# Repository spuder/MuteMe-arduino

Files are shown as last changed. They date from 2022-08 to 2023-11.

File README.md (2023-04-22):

# MuteMe-Arduino

MuteMe-Arduino is an open source implementation of the wildly popular [MuteMe hardware device](https://muteme.com/). 

Visually see if you are muted in a zoom/teams meeting, and control your microphone with the touch of a button. 



  









## CAD

Gerber files are available in the [Gerber](./Gerber/) directory, and available on [https://oshwlab.com/owenspencer/muteme-arduino](https://oshwlab.com/owenspencer/muteme-arduino)

PCB/BOM files are available in the [EasyEDA](./EasyEDA/) directory and available on  [https://oshwlab.com/owenspencer/muteme-arduino](https://oshwlab.com/owenspencer/muteme-arduino)

## Building

**Q: Should you build this?**

Most likely not. An official MuteMe-mini is only $19 with free shipping which is likely about the same or *more* than it would cost to bulid with an arduino. You are highly encouraged to support the origional creators. 

Where this project *does* make sense, is if you have a  mechanical keyboard or macro pad with a micro controller that supports HID emulation, and you want an embedded zoom button. 

- [Adafruit MacroPad](https://www.adafruit.com/product/5128)  
- [Adafruit FeatherWing](https://www.adafruit.com/product/4979)
- [Adafruit NeoPixel](https://www.adafruit.com/product/5020)
- [BYO Keybaord](https://painlessprototyping.com/byo-keyboard/)
- [BYO Keyboard 9 key](https://www.etsy.com/listing/1024993040/byo-9-key-keyboard-kit)

## Hardware

This project is designed around an Arduino Pro Mini, though any Arduino with a 32u4 chip should work (you may need to change pin assignments in the platformio.ini build flags. ItsyBitsy/Feather/Teensy should also work. 

- [Arduino Pro Mini](https://docs.arduino.cc/retired/boards/arduino-pro-mini)  
- [Arduino Pro Micro](https://store-usa.arduino.cc/products/arduino-micro)  
- [ItsyBitsy M0](https://www.adafruit.com/product/3727)  
- [Teensy](https://www.pjrc.com/teensy/)  

If you get a board working and want to add it to the `platformio.ini`, pull requests are welcomed and celebrated. 

### Arduino Pro Micro

On an arduino pro micro, connect the buttons and leds to the following pins. 
Put a ~300-400 ohm resistor on each leg of the RGB Led

You can use a common cathode or common anode LED. If using a common cathod you will need to change the variable `rgbLed_TYPE` 

```
#define BUTTON_PIN 2
#define RED_PIN	  6
#define BLUE_PIN  10
#define GREEN_PIN 9
#define rgbLed_TYPE RGBLed::COMMON_ANODE
```

Note: Pull up resistor on button is not required since Arduino Pro mini has internal pull up on pin 2



(Fritzing file available in the [fritzing](./fritzing/) directory)

## Tech Specs

It is possible to have up to 3 MuteMe devices connected to 1 computer simultaniously, as long as they each have a different VID/PID. The VID/PID MuteMe provides are shown below. 

This repo contains platform.io profiles for all 3. (More than likely you should use 'prototype'.) See [platformio.ini](./platformio.ini)

| Name | VID | PID|
|--- | --- | --- |
| Prototype | 0x16c0 | 0x27db |
| Origional | 0x20a0 | 0x42da | 
| Mini | 0x20a0 | 0x42db | 

Note that regardless of what model you choose, you will most likely see this warning. The official MuteMe devices have an undocumented method for differenciating between current models and the origional kickstarter models. If you figure out how to eliminate this warning, please open an issue or pull request. (Most likely the MuteMe software sends a challenge, or it could be detecting usagePage/usage/serial_number in the HID discriptor.)



Additional information available on the [MuteMe](https://muteme.com/pages/muteme-hid-key) website

Official MuteMe VendorID/ProductId/UagePage/Usage
```
hidapitester --list-detail

20A0/42DB: muteme.com - MuteMe-Mini
  vendorId:      0x20A0
  productId:     0x42DB
  usagePage:     0x0009
  usage:         0x0006
  serial_number:  
  interface:     0 
  path: IOService:/AppleARMPE/arm-io/AppleT600xIO/usb-drd1@2280000/AppleT6000USBXHCI@01000000/usb-drd1-port-hs@01100000/MuteMe-Mini@01100000/IOUSBHostInterface@0/AppleUserUSBHostHIDDevice
```

Compare to an arudino pro mini in USB_SERIAL_HID mode (2 virtual devices)

```
16C0/27DB: SparkFun - SparkFun Pro Micro
  vendorId:      0x16C0
  productId:     0x27DB
  usagePage:     0x0001
  usage:         0x0006
  serial_number: CHIDLD 
  interface:     3 
  path: IOService:/AppleARMPE/arm-io/AppleT600xIO/usb-drd2@2280000/AppleT6000USBXHCI@02000000/usb-drd2-port-hs@02100000/USB2.0 Hub@02100000/AppleUSB20Hub@02100000/AppleUSB20HubPort@02110000/SparkFun Pro Micro@02110000/IOUSBHostInterface@3/AppleUserUSBHostHIDDevice

16C0/27DB: SparkFun - SparkFun Pro Micro
  vendorId:      0x16C0
  productId:     0x27DB
  usagePage:     0xFFC0
  usage:         0x0C00
  serial_number: CHIDLD 
  interface:     2 
  path: IOService:/AppleARMPE/arm-io/AppleT600xIO/usb-drd2@2280000/AppleT6000USBXHCI@02000000/usb-drd2-port-hs@02100000/USB2.0 Hub@02100000/AppleUSB20Hub@02100000/AppleUSB20HubPort@02110000/SparkFun Pro Micro@02110000/IOUSBHostInterface@2/AppleUserUSBHostHIDDevice
  ```

### Input

The MuteMe software sends single hex bytes to the device which lights up a corresponding LED. 

```
red = 0x01
green = 0x02
yellow = 0x03
blue = 0x04
purple(magenta) = 0x05
cyan = 0x06
white = 0x07
noColor = 0x00
```

Note, `noColor` on the official devices actually requires 2 bytes `0x00 0x00`

Data is read using the awesome [HID-Project library](https://github.com/NicoHood/HID). 

```
    while (bytesAvailable--) {
      auto data = RawHID.read();
```

You can view the data that MuteMe software sends with the fantastic [hidapitester](https://github.com/todbot/hidapitester) app

Examples: 

Turn LED Blue
```
# Change '20A0/42DB' to your appropriate VID/PID
hidapitester --list-detail
hidapitester --vidpid 20A0/42DB --open --length 1 --send-feature 0x04 --close
```

Turn LED Magenta with fast blink
```

hidapitester --vidpid 20A0/42DB --open --length 1 --send-feature 0x25 --close
```

Turn off LED
```
hidapitester --vidpid 20A0/42DB --open --length 2 --send-feature 0,0 --close
```

### Output

The physical device sends 4 bytes back to the Mute Me software. 

**Note: MuteMe and hidapitester will have conflicts. You must close the MuteMe software to view output from the physical device** 

Note that while we only need to send 4 bytes, [there is a bug in the HID-Project library](https://github.com/NicoHood/HID/issues/133) that requires `64` bytes be sent. 

02 = Button was released event
```
hidapitester --vidpid 20A0/42DB --open --length 4 --read-input

Opening device, vid/pid: 0x20A0/0x42DB
Reading 64-byte input report 0, 250 msec timeout...read 8 bytes:
 00 00 00 02
Closing device
```

To watch all events as they stream by
```
hidapitester --vidpid 20A0:42DB --open --length 64 --read-input-forever --close
```

When 'holding' the button, MuteMe devices send `0x00 0x00 0x00 0x01` every few hundred milliseconds. 
To prevent overwhelming the USB bus with unneccessary data, MuteMe-Arduino sends that byte every 100 milliseonds which seems to be frequent enough. 

```
Reading 64-byte input report 0, 250 msec timeout...read 8 bytes:
 00 00 00 04 00 00 00 00 00 00 00 00 00 00 00 00 00 00 00 00 00 00 00 00 00 00 00 00 00 00 00 00
 00 00 00 00 00 00 00 00 00 00 00 00 00 00 00 00 00 00 00 00 00 00 00 00 00 00 00 00 00 00 00 00
Reading 64-byte input report 0, 250 msec timeout...read 8 bytes:
 00 00 00 01 00 00 00 00 00 00 00 00 00 00 00 00 00 00 00 00 00 00 00 00 00 00 00 00 00 00 00 00
 00 00 00 00 00 00 00 00 00 00 00 00 00 00 00 00 00 00 00 00 00 00 00 00 00 00 00 00 00 00 00 00
Reading 64-byte input report 0, 250 msec timeout...read 8 bytes:
 00 00 00 01 00 00 00 00 00 00 00 00 00 00 00 00 00 00 00 00 00 00 00 00 00 00 00 00 00 00 00 00
 00 00 00 00 00 00 00 00 00 00 00 00 00 00 00 00 00 00 00 00 00 00 00 00 00 00 00 00 00 00 00 00
 ```

## Debugging

Note: The MuteMe software can only _receive_ input from the arduino if there is only 1 UID per device (e.g. `build_flags = -D USB_HID`). 
Attempting to use `build_flags = -D USB_SERIAL_HID` will allow you to add debugging statements like `Serial.println()`, however it may result in multiple HID devices being registered on a single USB port which can confuse Mute Me software. Any button presses may not be detected by the Mute Me Software while in Serial mode. If you know a way to work arround this limitation, pull requests are welcome and encouraged. 

## Warning

This project is provided for educational purposes only. Comercial products are prohibited.  

MuteMe-Arduino is licensed under the [Creative Commons Non Commercial ShareAlike](https://creativecommons.org/licenses/by-nc-sa/4.0/) license.

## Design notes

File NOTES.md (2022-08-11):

# ZoomMute

Use a microcontroller to mute zoom meetings

## Resources

- [Get PID/VID of usb device](https://kb.synology.com/en-ph/DSM/tutorial/How_do_I_check_the_PID_VID_of_my_USB_device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,view%20its%20PID%20and%20VID.)

Arduino nano

```
  Product ID:	0x0487
  Vendor ID:	0x16c0
```

Mute Me

| Name | VID | PID|
|--- | --- | --- |
| Prototype | 0x16c0 | 0x27db |
| Origional | 0x20a0 | 0x42da | 
| Mini | 0x20a0 | 0x42db | 

Find the boards.txt and change settings

```
mdfind boards.txt
/Users/spencer.owen/Library/Arduino15/packages/arduino/hardware/avr/1.8.5/boards.txt
/Users/spencer.owen/Library/Arduino15/packages/esp8266/hardware/esp8266/3.0.2/tools/boards.txt.py
/Users/spencer.owen/Library/Arduino15/packages/esp8266/hardware/esp8266/3.0.2/boards.txt
/Users/spencer.owen/Code/github/spuder/klipper/docs/Bootloaders.md
```

- https://community.platformio.org/t/changing-usb-device-vid-pid/3986/17

List USB Devices (OSX)

`system_profiler SPUSBDataType`

```
USB Serial:

  Product ID: 0x0483
  Vendor ID: 0x16c0
  Version: 2.71
  Serial Number: 12345
  Speed: Up to 12 Mb/s
  Manufacturer: Teensyduino
  Location ID: 0x01110000 / 5
  Current Available (mA): 500
  Current Required (mA): 100
  Extra Operating Current (mA): 0
```

Setting Product ID and Vendor ID

- Use FT Prog (windows only) https://ftdichip.com/utilities/

https://community.platformio.org/t/changing-usb-device-vid-pid/3986/23?u=owenspencer

HID Data

Once every 5 seconds, MuteMe sends the following

- 19
- 83

Unmuting

- 23
- 87

Muting

- 19
- 83

https://www.hackster.io/abratchik/hid-compliant-ups-with-arduino-75198c

The creator of the Arduino HID library doesn't support it and recomends the adafruit LUFA library
https://github.com/NicoHood/HID/issues/139#issuecomment-692211209

Change arduino to show up as a UPS
https://github.com/abratchik/HIDPowerDevice/blob/master/linux/98-upower-hid.rules

Macro Keyboard
http://www.retrobuiltgames.com/the-build-page/macro-keyboard-v2-0/macro-keyboard-v0-4/

## Debugging

There are multiple options for debugging USB Connections. All options are terrible

Listed in order of least amount of terribleness

1. hidapitester https://github.com/todbot/hidapitester  
2. rawhid.py https://www.pjrc.com/teensy/rawhid.html  
3. rawhid (c++) https://www.pjrc.com/teensy/rawhid.html  

```
hidapitester --list
hidapitester --list-detail
hidapitester --vidpid 16C0/27DB --open --send-output 0x00
hidapitester --vidpid 16C0/27DB --usagePage 0001 --usage 0006 --open
hidapitester --vidpid 16C0/27DB --usagePage FFC0 --usage 0C00 --open #Note more than 1 sparkfun device may appear, use usagePage and Usage to more finely refine which one you want

hidapitester --vidpid 16C0/27DB --usagePage FFC0 --usage 0C00 --open --send-feature 01 --close
hidapitester --vidpid 16C0/27DB --usagePage FFC0 --usage 0C00 --open --send-feature 0x01 --close --length 64
hidapitester --vidpid 16C0/27DB --usagePage 0001 

```

```
16C0/27DB: SparkFun - SparkFun Pro Micro
  vendorId:      0x16C0
  productId:     0x27DB
  usagePage:     0x0001
  usage:         0x0006
  serial_number: CHIDLD 
  interface:     3 
  path: IOService:/AppleARMPE/arm-io/AppleT600xIO/usb-drd2@2280000/AppleT6000USBXHCI@02000000/usb-drd2-port-hs@02100000/USB2.0 Hub@02100000/AppleUSB20Hub@02100000/AppleUSB20HubPort@02110000/SparkFun Pro Micro@02110000/IOUSBHostInterface@3/AppleUserUSBHostHIDDevice

16C0/27DB: SparkFun - SparkFun Pro Micro
  vendorId:      0x16C0
  productId:     0x27DB
  usagePage:     0xFFC0
  usage:         0x0C00
  serial_number: CHIDLD 
  interface:     2 
  path: IOService:/AppleARMPE/arm-io/AppleT600xIO/usb-drd2@2280000/AppleT6000USBXHCI@02000000/usb-drd2-port-hs@02100000/USB2.0 Hub@02100000/AppleUSB20Hub@02100000/AppleUSB20HubPort@02110000/SparkFun Pro Micro@02110000/IOUSBHostInterface@2/AppleUserUSBHostHIDDevice
```

Example: Controlling LED with mute me mini (20A0/42DB)
```
# List Devices
hidapitester --list-detail

20A0/42DB: muteme.com - MuteMe-Mini
  vendorId:      0x20A0
  productId:     0x42DB
  usagePage:     0x0009
  usage:         0x0006
  serial_number:  
  interface:     0 
  path: IOService:/AppleARMPE/arm-io/AppleT600xIO/usb-drd1@2280000/AppleT6000USBXHCI@01000000/usb-drd1-port-hs@01100000/MuteMe-Mini@01100000/IOUSBHostInterface@0/AppleUserUSBHostHIDDevice
```

- You can use either `4` or `0x04` syntax
- You can send any length you like (1-255), but turning off requires length >=2 
```
# Turn LED Blue (0x04)
hidapitester --vidpid 20A0/42DB --open --length 2 --send-feature 0x04 --close

# Turn LED Purple with fast blink (0x05 + 0x20)
hidapitester --vidpid 20A0/42DB --open --length 2 --send-feature 0x25 --close

# Turn LED White
hidapitester --vidpid 20A0/42DB --open --length 1 --send-feature 0x07 --close

# Turn off LED (requires length >1). All the following syntaxes work
hidapitester --vidpid 20A0/42DB --open --length 2 --send-feature 0x00 0x00 --close
hidapitester --vidpid 20A0/42DB --open --length 2 --send-feature 0,0 --close
hidapitester --vidpid 20A0/42DB --open --length 2 --send-feature 0,0 --close
hidapitester --vidpid 20A0/42DB --open --length 2 --send-feature 0 --close
```

- Note that the input always ends on the 4th byte? Very curious
```
# Physically touch the MuteMe, then run the following 
# (you only have 1/4 of a second to catch it so its really hard to catch the touch/release events)
# This will capture 16 bytes
hidapitester --vidpid 20A0/42DB --open --length 17 --read-input 3

Opening device, vid/pid: 0x20A0/0x42DB
Reading 17-byte input report 0, 250 msec timeout...read 8 bytes:
 00 00 00 01 00 00 00 00 00 00 00 00 00 00 00 00 00
Closing device

hidapitester --vidpid 20A0/42DB --open --length 64 --read-input
```

```
# Captured a touch event (0x00 0x00 0x00 0x04)
hidapitester --vidpid 20A0/42DB --open --length 4 --read-input

Opening device, vid/pid: 0x20A0/0x42DB
Reading 64-byte input report 0, 250 msec timeout...read 8 bytes:
 00 00 00 04
Closing device
```

```
# Captured a release event (0x00 0x00 0x00 0x02)

hidapitester --vidpid 20A0/42DB --open --length 4 --read-input

Opening device, vid/pid: 0x20A0/0x42DB
Reading 64-byte input report 0, 250 msec timeout...read 8 bytes:
 00 00 00 02
Closing device
```

```
hidapitester --vidpid 20A0/42DB --close
```

16C0/27DB: SparkFun - SparkFun Pro Micro
  vendorId:      0x16C0
  productId:     0x27DB
  usagePage:     0xFFC0
  usage:         0x0C00
  serial_number: CHIDLD 
  interface:     2 
  path: IOService:/AppleARMPE/arm-io/AppleT600xIO/usb-drd2@2280000/AppleT6000USBXHCI@02000000/usb-drd2-port-hs@02100000/USB2.0 Hub@02100000/AppleUSB20Hub@02100000/AppleUSB20HubPort@02110000/SparkFun Pro Micro@02110000/IOUSBHostInterface@2/AppleUserUSBHostHIDDevice
16C0/27DB: SparkFun - SparkFun Pro Micro
  vendorId:      0x16C0
  productId:     0x27DB
  usagePage:     0x0001
  usage:         0x0006
  serial_number: CHIDLD 
  interface:     3 
  path: IOService:/AppleARMPE/arm-io/AppleT600xIO/usb-drd2@2280000/AppleT6000USBXHCI@02000000/usb-drd2-port-hs@02100000/USB2.0 Hub@02100000/AppleUSB20Hub@02100000/AppleUSB20HubPort@02110000/SparkFun Pro Micro@02110000/IOUSBHostInterface@3/AppleUserUSBHostHIDDevice

```
hidapitester --list-detail| grep -A 7 'SparkFun - SparkFun Pro Micro'

hidapitester --vidpid 16C0:27DB --usagePage FFC0 --usage 0C00 --open --length 4 --read-input --close

Opening device, vid/pid:0x16C0/0x27DB, usagePage/usage: FFC0/C00
Device opened
Reading 4-byte input report 0, 250 msec timeout...read 4 bytes:
 00 00 00 04
Closing device
```

```
hidapitester --vidpid 20A0/42DB --open

hidapitester --vidpid 20A0/42DB --usagePage 0009 --usage 0006 --open --length 4 --read-input --close
hidapitester --vidpid 20A0/42DB --open --length 4 --read-input --close

hidapitester --vidpid 20A0:42DB --open --length 4 --read-input --close

```

hidapitester --close

All this only works if the muteme app is closed ! 

hidapitester --vidpid 16C0:27DB --usagePage FFC0 --usage 0C00 --open --length 4 --read-input-forever --close

hidapitester --vidpid 20A0:42DB --open --length 64 --read-input-forever --close

Full touch sequence 04 (start touch), 01 (touching), 02 (end touch)

```
Reading 64-byte input report 0, 250 msec timeout...read 8 bytes:
 00 00 00 04 00 00 00 00 00 00 00 00 00 00 00 00 00 00 00 00 00 00 00 00 00 00 00 00 00 00 00 00
 00 00 00 00 00 00 00 00 00 00 00 00 00 00 00 00 00 00 00 00 00 00 00 00 00 00 00 00 00 00 00 00
Reading 64-byte input report 0, 250 msec timeout...read 8 bytes:
 00 00 00 01 00 00 00 00 00 00 00 00 00 00 00 00 00 00 00 00 00 00 00 00 00 00 00 00 00 00 00 00
 00 00 00 00 00 00 00 00 00 00 00 00 00 00 00 00 00 00 00 00 00 00 00 00 00 00 00 00 00 00 00 00
Reading 64-byte input report 0, 250 msec timeout...read 8 bytes:
 00 00 00 01 00 00 00 00 00 00 00 00 00 00 00 00 00 00 00 00 00 00 00 00 00 00 00 00 00 00 00 00
 00 00 00 00 00 00 00 00 00 00 00 00 00 00 00 00 00 00 00 00 00 00 00 00 00 00 00 00 00 00 00 00
Reading 64-byte input report 0, 250 msec timeout...read 8 bytes:
 00 00 00 01 00 00 00 00 00 00 00 00 00 00 00 00 00 00 00 00 00 00 00 00 00 00 00 00 00 00 00 00
 00 00 00 00 00 00 00 00 00 00 00 00 00 00 00 00 00 00 00 00 00 00 00 00 00 00 00 00 00 00 00 00
Reading 64-byte input report 0, 250 msec timeout...read 8 bytes:
 00 00 00 01 00 00 00 00 00 00 00 00 00 00 00 00 00 00 00 00 00 00 00 00 00 00 00 00 00 00 00 00
 00 00 00 00 00 00 00 00 00 00 00 00 00 00 00 00 00 00 00 00 00 00 00 00 00 00 00 00 00 00 00 00
Reading 64-byte input report 0, 250 msec timeout...read 8 bytes:
 00 00 00 01 00 00 00 00 00 00 00 00 00 00 00 00 00 00 00 00 00 00 00 00 00 00 00 00 00 00 00 00
 00 00 00 00 00 00 00 00 00 00 00 00 00 00 00 00 00 00 00 00 00 00 00 00 00 00 00 00 00 00 00 00
Reading 64-byte input report 0, 250 msec timeout...read 8 bytes:
 00 00 00 01 00 00 00 00 00 00 00 00 00 00 00 00 00 00 00 00 00 00 00 00 00 00 00 00 00 00 00 00
 00 00 00 00 00 00 00 00 00 00 00 00 00 00 00 00 00 00 00 00 00 00 00 00 00 00 00 00 00 00 00 00
Reading 64-byte input report 0, 250 msec timeout...read 8 bytes:
 00 00 00 01 00 00 00 00 00 00 00 00 00 00 00 00 00 00 00 00 00 00 00 00 00 00 00 00 00 00 00 00
 00 00 00 00 00 00 00 00 00 00 00 00 00 00 00 00 00 00 00 00 00 00 00 00 00 00 00 00 00 00 00 00
Reading 64-byte input report 0, 250 msec timeout...read 8 bytes:
 00 00 00 01 00 00 00 00 00 00 00 00 00 00 00 00 00 00 00 00 00 00 00 00 00 00 00 00 00 00 00 00
 00 00 00 00 00 00 00 00 00 00 00 00 00 00 00 00 00 00 00 00 00 00 00 00 00 00 00 00 00 00 00 00
Reading 64-byte input report 0, 250 msec timeout...read 8 bytes:
 00 00 00 02 00 00 00 00 00 00 00 00 00 00 00 00 00 00 00 00 00 00 00 00 00 00 00 00 00 00 00 00
 00 00 00 00 00 00 00 00 00 00 00 00 00 00 00 00 00 00 00 00 00 00 00 00 00 00 00 00 00 00 00 00
Reading 64-byte input report 0, 250 msec timeout...read 8 bytes:
 00 00 00 00 00 00 00 00 00 00 00 00 00 00 00 00 00 00 00 00 00 00 00 00 00 00 00 00 00 00 00 00
 00 00 00 00 00 00 00 00 00 00 00 00 00 00 00 00 00 00 00 00 00 00 00 00 00 00 00 00 00 00 00 00
 ```

 Need to hook arduino up to pin that supports external interupts

 https://learn.sparkfun.com/tutorials/pro-micro--fio-v3-hookup-guide/hardware-overview-pro-micro

 Arudino Pro Micro has

 - pin 3 = INT 0
 - pin 2 = INT 1
 - pin 0 = INT 2
 - pin 1 = INT 3
 - pin 7 = INT 4

https://learn.sparkfun.com/tutorials/pro-micro--fio-v3-hookup-guide/hardware-overview-pro-micro

USB VID:PID=16C0:27DB SER=C LOCATION=1-1.1

hidapitester --vidpid 16C0:27DB --open
hidapitester --vidpid 16C0:27DB --open --length 64 --read-input-forever --close
hidapitester --vidpid 16C0/27DB --usagePage FFC0 --usage 0C00 --open --length 64 --read-input-forever --close
hidapitester --vidpid 16C0:27DB --usagePage FFC0 --usage 0C00 --open --length 64 --read-input-forever --close

hidapitester --vidpid 16C0:27DB --open --length 64 --read-input-forever --close

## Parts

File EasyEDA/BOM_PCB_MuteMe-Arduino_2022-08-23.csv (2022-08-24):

ID | Name | Designator | Footprint | Quantity | Manufacturer Part | Manufacturer | Supplier | Supplier Part | Price
1 | OSHW-LOGO-M | 5 | OSHW-LOGO-M | 1
2 | CHERRYMX | S1 | CHERRYMX | 1 | CherryMX
3 | LED-TRICOLOR-THROUGHHOLE | 1,2,3 | LED-TRICOLOR-THROUGHHOLE | 3
4 | SM101031504FE | R1,R2,R3 | RES-TH_L6.4-W1.8-P5.08-D0.6 | 3 | SM101031504FE | Ohmite | LCSC | C3577345 | 1.584
5 | ArduinoProMicroATmega32U4USB | U1 | ARDUINOPROMICROUSB | 1

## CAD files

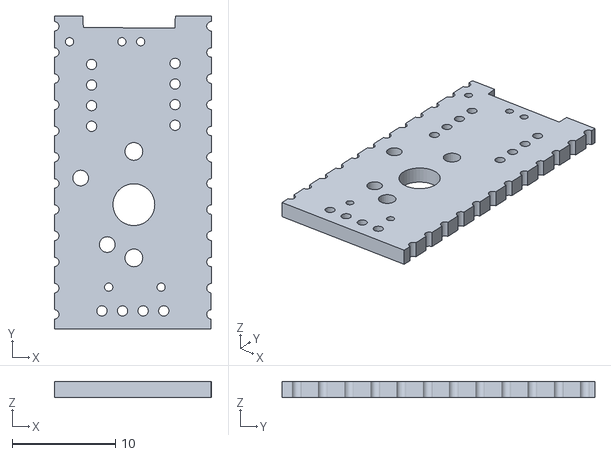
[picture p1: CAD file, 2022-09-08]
CAD/PCB.stl
15.3 x 30.4 x 1.60

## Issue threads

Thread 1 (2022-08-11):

Clear 0x00 doesn't work

spuder, 2022-08-11:
All of the following syntax will turn off a real MuteMe device

```
hidapitester --vidpid 20A0/42DB --open --length 2 --send-feature 0x00 0x00 --close
hidapitester --vidpid 20A0/42DB --open --length 2 --send-feature 0,0 --close
hidapitester --vidpid 20A0/42DB --open --length 2 --send-feature 0,0 --close
hidapitester --vidpid 20A0/42DB --open --length 2 --send-feature 0 --close
```

Add support for receiving multiple byte HID data streams `0x00 0x00` and translate that to `led.off();`

```
    while (bytesAvailable--) {
      auto hidData = RawHID.read();
      #ifdef DEBUG
        Serial.print(hidData, HEX); //TODO: Neither HEX nor DEC print properly
        Serial.println(" ");
      #endif
      muteMe2Color(hidData);
      // TODO: Support multiple bytes 0x00 0x00 (clear)
    }
```

spuder, 2022-08-11:
I tried this workaround but it is too aggressive
```
      if (sizeof(hidData) > 1) {
          rgbLed.off();
      }
```

```
    while (bytesAvailable--) {
      auto hidData = RawHID.read();
      #ifdef DEBUG
        Serial.print(hidData, HEX); //TODO: Neither HEX nor DEC print properly
        Serial.println(" ");
      #endif
      muteMe2Color(hidData);
      if (sizeof(hidData) > 1) {
          rgbLed.off();
      }
    }
  }
```

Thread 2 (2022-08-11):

Button presses have slight delay

spuder, 2022-08-11:
The button _feels_ slow to respond. Most likely this is because we are using polling to detect if the user is holding the button.

Theories
1. Serial.println is taking too long

I've tried both debug and non debug builds (non debug builds don't have any serial.println statements since they are wrapped in if statements). Both _feel_ slow

2. Debounce is too long or too short

I've tried values from 30 up to 250

```
  if (millis() - buttonCheckMillis > 50) {
    buttonCheckMillis = millis();
```

Shorter values _feel_ less responsive. Maybe because of all the serial.println?
Longer values like 250 didn't seem to help either.

I looked at how other button libraries handle debouncing and they do values between 30ms and 60ms

```
void loop()
{
  // User pressed the button
  if (button1.toggled()) {
    if (button1.read() == Button::PRESSED) {
        #ifdef DEBUG
          Serial.println("Button Pressed");
        #endif
        rawhidData[3] = 0x04; // Touch Button
        RawHID.write(rawhidData, sizeof(rawhidData));
        rawhidData[3] = 0x00;
    }
    // User released the button
    else {
        #ifdef DEBUG
          Serial.println("Button Released");
        #endif
        rawhidData[3] = 0x02; // Release Button
        RawHID.write(rawhidData, sizeof(rawhidData));
        rawhidData[3] = 0x00;
    }
  }
  // Poll every 50 milliseconds to see if user is still holding button
  // TODO: This is a little slow. Find a way to make it more responsive.
  if (millis() - buttonCheckMillis > 50) {
    buttonCheckMillis = millis();
    if (button1.read() == Button::PRESSED) {
        #ifdef DEBUG
          Serial.println("Button Held");
        #endif
        rawhidData[3] = 0x01; // Hold Button
        RawHID.write(rawhidData, sizeof(rawhidData));
        rawhidData[3] = 0x00;
    }
  }
```

spuder, 2022-08-11:
Here is an output of pushing the button quickly. The button is still showing as pressed for several hundred milliseconds

```
Ignoring data61
21
61
Ignoring data61
21
61
Ignoring data61
21
61
Ignoring data61
Button Pressed
Button Held
Button Held
Button Held
Button Held
Button Held
Button Held
Button Held
Button Held
Button Held
Button Held
Button Released
4
44
Ignoring data44
21
61
```

spuder, 2022-08-17:
Fixed in 6af001c2986b8d52ebef22e524056129510b8912

switched to Button2 library with callback functions. Much snappy now

Closed 2022-08-17.

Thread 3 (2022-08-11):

Supress warning in software

spuder, 2022-08-11:
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

Regardless which type you do (prototype, mini, origional) you get this warning frequently in the software. Checking the box to ignore doesn't work.

## Theories

1. Software is sending a challenge bit that only the newer firmwares know how to respond to.
Try doing a --read-input-forever to capture that if it is the case. Then we can send the appropriate response.
```
hidapitester --vidpid 20A0:42DB --open --length 64 --read-input-forever --close
```

2. Sofware is looking at device name

```
hidapitester --list-detail

20A0/42DB: muteme.com - MuteMe-Mini
  vendorId:      0x20A0
  productId:     0x42DB
  usagePage:     0x0009
  usage:         0x0006
  serial_number:
  interface:     0
  path: IOService:/AppleARMPE/arm-io/AppleT600xIO/usb-drd1@2280000/AppleT6000USBXHCI@01000000/usb-drd1-port-hs@01100000/MuteMe-Mini@01100000/IOUSBHostInterface@0/AppleUserUSBHostHIDDevice
```
```
16C0/27DB: SparkFun - SparkFun Pro Micro
  vendorId:      0x16C0
  productId:     0x27DB
  usagePage:     0xFFC0
  usage:         0x0C00
  serial_number: C
  interface:     2
  path: IOService:/AppleARMPE/arm-io/AppleT600xIO/usb-drd2@2280000/AppleT6000USBXHCI@02000000/usb-drd2-port-hs@02100000/USB2.0 Hub@02100000/AppleUSB20Hub@02100000/AppleUSB20HubPort@02110000/SparkFun Pro Micro@02110000/IOUSBHostInterface@2/AppleUserUSBHostHIDDevice
```

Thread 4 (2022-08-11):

Breathing effect improvements

spuder, 2022-08-11:
The current breathing light goes from 0% to 100%.

Change it so it matches the official mute me

- [ ] Breathing slow
- [ ] Breathing fast

https://makersportal.com/blog/2020/3/27/simple-breathing-led-in-arduino

May need to convert to the FastLED library since the RGBLed library can't limit min brightness

spuder, 2022-08-11:
https://user-images.githubusercontent.com/242382/184261391-9ba8cd16-b8ee-476c-a5a6-3a1c2333ea8c.MOV

https://user-images.githubusercontent.com/242382/184261399-7f817831-71d4-4224-99cc-0cbe34375692.MOV

spuder, 2022-08-12:
Slow = 2.35 seconds

Values between 460 and 470 are pretty close

```
// RGB LED Circle Wave Breathing LED

int led_pins[1] = {3};
int jj = 0; // 0 = red, 1 = green, 2 = blue
float smoothness_pts = 463;//larger=slower change in brightness

void setup() {

  pinMode(2, INPUT_PULLUP);
  Serial.begin(9600);
  for (int ii = 0;ii<sizeof(led_pins)/sizeof(int);ii++){
    pinMode(led_pins[ii],OUTPUT);
  }
}

void loop() {

  for (int ii=0;ii<smoothness_pts;ii++){
    float pwm_val = 255.0*sqrt(1.0 -  pow(abs((2.0*(ii/smoothness_pts))-1.0),2.0));
    analogWrite(led_pins[jj],int(pwm_val));
    auto pin = digitalRead(2);
    if (pin == LOW) {
      ii=0;
    }
    delay(5);
//    Serial.println(int(pwm_val));
  }
}
```

spuder, 2022-08-12:
https://github.com/wilmouths/RGBLed/issues/9

spuder, 2022-08-12:
Current breathing is blocking

https://avital.ca/notes/a-closer-look-at-apples-breathing-light

spuder, 2022-08-12:
The gausian is very pleasing, however it is too subtile compared to the official mute me. The mute me has more of an urgency feeling to it

```
// RGB LED Gaussian Wave Breathing LED

int led_pins[4] = {3,5,6};
int jj = 1; // 0 = red, 1 = green, 2 = blue
float smoothness_pts = 500;//larger=slower change in brightness

float gamma = 0.14; // affects the width of peak (more or less darkness)
float beta = 0.5; // shifts the gaussian to be symmetric

void setup() {
  Serial.begin(9600);
  for (int ii = 0;ii<sizeof(led_pins)/sizeof(int);ii++){
    pinMode(led_pins[ii],OUTPUT);
  }
}

void loop() {
  for (int ii=0;ii<smoothness_pts;ii++){
    float pwm_val = 255.0*(exp(-(pow(((ii/smoothness_pts)-beta)/gamma,2.0))/2.0));
    analogWrite(led_pins[jj],int(pwm_val));
    delay(5);
    Serial.println(int(pwm_val));
  }
}
```

spuder, 2022-08-12:
This is _really_ _really_ close. After a few minutes it is too slow

```cpp
#include <math.h>

void setup() {
  pinMode(6, OUTPUT);
  Serial.begin(9600);
}

void loop() {
  auto period = 1200.0;// 2000.0
  float val = (exp(sin(millis()/period * PI)) - 0.368) * 108.0;
  Serial.print(0);
  Serial.print(" ");
  Serial.print(val);
  Serial.print(" ");
  Serial.println(255);
  analogWrite(6, val);
}
```

spuder, 2022-08-13:
Here is how this library solves it. Note that it only runs the calculation once per millisecond

https://github.com/SethSenpai/singleLEDLibrary/blob/master/singleLEDLibrary.cpp#L108-L112

spuder, 2022-08-13:
I tried to pregenerate all the values, but it takes too much memory.

```cpp

float ledBrightnessTable[2400];

float table[2400];
auto now = millis();
auto counter = 0;

void setup() {

  while (millis() < (now + 2400)) {

    if (now != millis() ) {
      auto period = 1200.0;// 2000.0
      float val = (exp(sin(millis()/period * PI)) - 0.368) * 108.0;
      table[counter] = val;
      counter++;
      now=millis();
    }

  }

  Serial.begin(9600);
  Serial.print("Generated table");
  for (auto i = 0; i < sizeof(table); i++) {
    Serial.print(table[i]);
    Serial.print(',');
  }
}

void loop() {

}
```

spuder, 2022-08-14:
New problem. Whenever the values is ~ 127 the led turns off for a split second.

```cpp
void Led::pulse(int period) {
    if((last_refresh_time + 1) < millis() ){
        last_refresh_time = millis();
        // https://thingpulse.com/breathing-leds-cracking-the-algorithm-behind-our-breathing-pattern/
        float min =  0.36787944;
        float amplitude = 42.54590641;
        uint8_t b = (exp(sin(millis()/(float)period*PI)) - min)* amplitude;
        this->brightness = (byte)b * 255 / 100;
        Serial.print(0);
        Serial.print(" ");
        Serial.print(255);
        Serial.print(" ");
        Serial.print(127);
        Serial.print(" ");
        Serial.println(this->brightness);

        byte red_brightness = (mapRed(this->color) * this->brightness) / 100;
        byte green_brightness = (mapGreen(this->color) * this->brightness) / 100;
        byte blue_brightness = (mapBlue(this->color) * this->brightness) / 100;

        invertAnalogWrite(this->red_pin, red_brightness);
        invertAnalogWrite(this->green_pin, green_brightness);
        invertAnalogWrite(this->blue_pin, blue_brightness);
    }
}
```
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

Here is a dump of the data. I expect to see a 0 somwhere around 127, but I never see that. There doesn't appear to be any gaps that would explain why the LED turns off briefly in the pulse sequence. (Captured at 115200)

[output.txt](https://github.com/spuder/MuteMe-arduino/files/9334165/output.txt)

spuder, 2022-08-14:
This does _not_ clip

```
#include <math.h>

void setup() {
  pinMode(6, OUTPUT);
  Serial.begin(9600);
}

void loop() {
  //1300 = slower
  //1100 = faster
  auto period = 1200.0;// 2000.0
//  float val = (exp(sin(millis()/period * PI)) - 0.368) * 108.0;

  float min =  0.381966011;
  float amplitude = 42.0; //42.54590641;
  uint8_t b = (exp(sin(millis()/(float)period*PI)) - min)* amplitude;
  b = b * 255 / 100;

  Serial.print(0);
  Serial.print(" ");
  Serial.print(255);
  Serial.print(" ");
  Serial.print(127);
  Serial.print(" ");
  Serial.println(b);
  analogWrite(6, 255 - b);
}
```

spuder, 2022-08-14:
Solved with constrain `  b = constrain(b * 255 / 100, 0, 255) ; `

```cpp
#include <math.h>

void setup() {
  pinMode(6, OUTPUT);
  Serial.begin(9600);
}

void loop() {
  //1300 = slower
  //1100 = faster
  auto period = 1200.0;// 2000.0

  float min =  0.25; // how curved the bell is (also has an impact on max altitude)
  float amplitude = 42.0; //42.54590641;
  uint8_t b = (exp(sin(millis()/(float)period*PI)) - min)* amplitude;
  b = constrain(b * 255 / 100, 0, 255) ;

  Serial.print(0);
  Serial.print(" ");
  Serial.print(255);
  Serial.print(" ");
  Serial.print(127);
  Serial.print(" ");
  Serial.println(b);
  analogWrite(6, 255 - b);
}

```

spuder, 2022-08-15:
I tried to create a histogram showing the function. Unfortunatly 30 frames per second just isn't that much data ( I really need data every 10/100 milliseconds).

Convert video to images
```shell
docker run -it --entrypoint /bin/bash --workdir /data -v $PWD:/data linuxserver/ffmpeg:version-4.4-cli
ffmpeg -i ../breathing-left.mp4 %04d.png
```

Convert images to histogram
```shell
docker run -it  -v $PWD:/data --workdir /data --entrypoint /bin/bash dpokidov/imagemagick
# https://stackoverflow.com/a/51332870/1626687
function foobar {
echo "$1" && convert "$1" -colorspace HSI -channel b -separate +channel -scale 1x1 -format "%[fx:100*u]\n" info: >> /tmp/foobar.txt;
}
export -f foobar
rm /tmp/foobar.txt
find . -type f -name "*.png" -exec bash -c 'foobar "$1"' _ {} \;
cp /tmp/foobar.txt /data
```
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

Nevertheless it still appears to be a gaussian or a sinusoid function

https://makersportal.com/blog/2020/3/27/simple-breathing-led-in-arduino

[foobar.txt](https://github.com/spuder/MuteMe-arduino/files/9334885/foobar.txt)

spuder, 2022-08-15:
This is pretty good. It never goes fully dark. However it is blocking which isn't ideal

```cpp
// RGB LED Gaussian Wave Breathing LED

int led_pins[1] = {10};
int jj = 1; // 0 = red, 1 = green, 2 = blue
float smoothness_pts = 485;//larger=slower change in brightness

float gamma = 0.250; // affects the width of peak (more or less darkness)
float beta = 0.5; // shifts the gaussian to be symmetric

void setup() {
  Serial.begin(9600);
  for (int ii = 0;ii<sizeof(led_pins)/sizeof(int);ii++){
    pinMode(led_pins[ii],OUTPUT);
  }
}

void loop() {
  for (int ii=0;ii<smoothness_pts;ii++){
    float pwm_val = 255.0*(exp(-(pow(((ii/smoothness_pts)-beta)/gamma,2.0))/2.0));
    analogWrite(led_pins[jj],255-int(pwm_val));
    delay(5);
    Serial.println(255-int(pwm_val));
  }
}
```
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

spuder, 2022-08-16:
More testing. I setup a 2400 second loop and discovered that the period isn't exactly 2400 seconds. After 20-30 loops the leds get out of sync. 🤔 The ramp up and ramp down might be different durations.

```cpp
void setup() {
  pinMode(6, OUTPUT);
}

void loop() {
  analogWrite(6, 0);
  delay(1200);
  analogWrite(6, 255);
  delay(1200);
}
```

spuder, 2022-08-16:
Tried to visualize the graph with processing.

```cpp
String[] data;
float[] newData;
int x = 100;
int counter = 0;
void setup() {
  frameRate(24);
  data = loadStrings("/Users/spencer.owen/Desktop/muteme-single-wave.txt");
  newData = new float[data.length];
  for (int i = 0; i < data.length; i++) {
    print("data: ");
    print(data[i]);
    newData[i] = map(float(data[i]),42.0, 66.0, 0, 255);
    print(" newData: ");
    print(newData[i]);
    println();
  }
  size(400, 400);
  noStroke();
}
void draw() {
  background(155);
  ellipse(counter, newData[counter], 50, 50);
  if (counter+1 >= newData.length) {
    counter = 0;
  }
  else {
    counter++;
  }
}

```

I'm realizing that only capturing 30fps on the phone isn't enough data points

https://user-images.githubusercontent.com/242382/184798221-5c4b51ce-f0f5-49e9-8682-b0c6484ddc90.mov

spuder, 2022-08-16:
I refilmed at 240 hertz (slow mo) on my iphone with locked exposure.
I believe my phone was compensating exposure which would explain why the top of the wave looked slanted.

Running for ~12 seconds gave 2305 datapoints.

```
cd ~/Desktop/breathing
docker run -it --entrypoint /bin/bash --workdir /data -v $PWD:/data linuxserver/ffmpeg:version-4.4-cli
ffmpeg -i ./breathing-slowmo.mov %04d.png
```

```
docker run -it  -v $PWD:/data --workdir /data --entrypoint /bin/bash dpokidov/imagemagick
# https://stackoverflow.com/a/51332870/1626687
function foobar {
echo "$1" && convert "$1" -colorspace HSI -channel b -separate +channel -scale 1x1 -format "%[fx:100*u]\n" info: >> /tmp/foobar.txt;
}
export -f foobar
rm /tmp/foobar.txt
find . -type f -name "*.png" -exec bash -c 'foobar "$1"' _ {} \;
cp /tmp/foobar.txt /data
```
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

spuder, 2022-08-16:
I can see how it is clipping/flickering, but no idea why
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
[clipping.txt](https://github.com/spuder/MuteMe-arduino/files/9355239/clipping.txt)

spuder, 2022-08-16:
Timed several more and found 10 pulses exactly equaled 23.5 seconds.

23.5 * 6 = 141 pulses per minute

spuder, 2022-08-17:
Fixed studdering

`byte red_brightness = (mapRed(this->color) * this->brightness) / 100;`

Should be
`byte red_brightness = (mapRed(this->color) * this->brightness) / 255;`

spuder, 2022-08-17:
Additional tests on the period

```
1175 should theoretically be exact, but feels fast
1175 = 23.4 seconds for 10 cycles
1180 = 23.6 seconds for 10 cycles
1190 = 23.8 seconds for 10 cycles
1200 = 23.8 seconds for 10 cycles
1202 = 23.84 seconds for 10 cycles
1210 = 24.3 seconds for 10 cycles
1205 = 23.93 seconds for 10 cycles

mute me = 23.9 seconds for 10 cycles
mute me = 23.9 seconds for 10 cycles
mute me = 23.9 seconds for 10 cycles
```

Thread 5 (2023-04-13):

Led problem on Windows10

gianmarco-mameli, 2023-04-13:
Hi spuder, thanks for this awesome project, I've forked your repo and configured 2 variants, one for an Arduino Pro Micro connected to a Neopixel ring light, and one for a Adafruit Trinkey.
All work like a charm in my mac machine, but when i try to use the devices on a windows machine for work, only the button part works, the led stays off.
I've tried to monitor the output with platformio and vscode, and the rawhid data arrives empty, like 0/0 and similar.
Do you have any idea why is not working, or if maybe it's more appropriate to open the issue on the nicohood/hid project

Thanks

spuder, 2023-04-13:
I'm so glad you found the project and are trying this out. NeoPixels do make a lot of sense. I don't know why I didn't do that initially.

I've not tested this on windows, only mac; however the protocol theoretically should be the same. I've not seen anything in the [mute me technical docs](https://muteme.com/pages/muteme-hid-key?_pos=1&_sid=2af9f1e4c&_ss=r) that would behave differently on windows.

A couple of ideas
1. I'll plug mine into a windows computer and see if I get the same results
2. USB power limitations?
3. Driver need to be installed?
4. Which HID is in use? Try original instead of prototype

5. Does hidutil run on windows? If so it would be interesting to see a full dump

```
hidapitester --vidpid 20A0:42DB --open --length 64 --read-input-forever --close
```

6. Can you write to the LED manually?

```
hidapitester --vidpid 20A0/42DB --open --length 1 --send-feature 0x25 --close
```

7. What version of muteme software? They may have broken the 'prototype' functionality.

spuder, 2023-04-14:
I just tested my arduino mute me and I'm seeing the same behavior.

The LED doesn't light up on windows, but it does on Mac.

My suggestion is to compile with DEBUG enabled to try and see what is happening.

I suspect windows is using a different frame size so the 64 bits it is expecting is not being received (main.cpp line 115)

gianmarco-mameli, 2023-04-17:
Hi, this is the repeated output on a windows machine with debug mode on, and the muteme app open
```
parseEffect: 0
bright
hidData: 0 / 0
ones: 0 / 0
tens: 0 / 0

parseEffect: 0
bright
hidData: 0 / 0
ones: 0 / 0
tens: 0 / 0
```

As mentioned before the button works perfectly, but the led don't

cbattlegear, 2023-04-21:
I am also seeing this issue too (building on a Trinket M0) Button is working but led is not, currently seeing mostly 0/0 spam, but I do see some outputs of:

Invalid/Undocumented data: 80/8
Invalid/Undocumented data: 812/C8
Invalid/Undocumented data: 111/1B

Running MuteMe-Client v0.15.2.stable (win_64)

What info would you like on the hidapitester? I essentially just see a bunch of "zeros"

I did do a USB trace on the device out of curiosity and I am seeing 36 BULK_OR_INTERRUPT_TRANSFER messages between every normal class.

Any other info you need happy to help, I am going to keep digging into this to see if I can pull anything together.

cbattlegear, 2023-04-21:
Quick update, patched in reading 64k every message and it is working perfectly now, will clean my code up (added a bunch of testing garbage and a DotStar) and see if I can throw in a PR.

gianmarco-mameli, 2023-04-22:
Hi, thank you great, i'll wait for your mod. When I'm sure all it's ok i'm going to clean up my code and commit the NeoPixel and Trinkey variations

spuder, 2023-04-22:
Awesome work! I'm so glad you found that.

spuder, 2023-04-25:
Thanks so much for your help.
I'll close this issue since it looks like #6 has fixed the LED issue on both windows and mac.

Also, as a side note, I've linted the code with `clang-format -i src/*.cpp`, so if you open a PR for neopixel support you may want to lint first to avoid conflicts. (Eventually I'll figure out why automatic linting isn't working in #7 )

Closed 2023-04-25.

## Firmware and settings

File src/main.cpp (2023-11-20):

/**

 */
#include "Arduino.h"
#include "Button2.h"
#include "HID-Project.h"
#include "Led.h"

#ifdef NEOPIXEL
#define BUTTON_PIN 9
#define BUTTON_PWR 2

#include <LedNeoPixel.h>

LedNeoPixel Led;

#else

#include "Led.h"

#define BUTTON_PIN 2
#define RED_PIN 6
#define GREEN_PIN 9
#define BLUE_PIN 10
Led Led(RED_PIN, GREEN_PIN, BLUE_PIN);
#endif

Button2 button;
// These are automatically zero initialized
// This is our output buffer used by button presses
byte rawhidWriteBuffer[64];
// This is our input buffer used by RawHID
byte rawhidInBuffer[64];
// This is our 64b buffer to make sure we get 64b of input before processing
byte rawhidBuffer[64];
// Byte count to track input
int byte_count = 0;

void pressed(Button2 &btn) {
  rawhidWriteBuffer[3] = 0x04;  // Touch Button
  RawHID.write(rawhidWriteBuffer, sizeof(rawhidWriteBuffer));
  rawhidWriteBuffer[3] = 0x00;
  // #ifdef DEBUG
  // Serial.println("pressed");
  // #endif
}

void released(Button2 &btn) {
  rawhidWriteBuffer[3] = 0x02;  // Release Button
  RawHID.write(rawhidWriteBuffer, sizeof(rawhidWriteBuffer));
  rawhidWriteBuffer[3] = 0x00;
  // #ifdef DEBUG
  // Serial.print("released: ");
  // Serial.println(btn.wasPressedFor());
  // #endif
}

void longClickDetected(Button2 &btn) {
  rawhidWriteBuffer[3] = 0x01;  // Hold Button
  RawHID.write(rawhidWriteBuffer, sizeof(rawhidWriteBuffer));
  rawhidWriteBuffer[3] = 0x00;
  #ifdef DEBUG
  Serial.println("long click detected\n");
  #endif
}

void parseColor(int data) {
    switch (data) {
        case 0:
            Led.setColor(LedColor::no_color);
            break;
        case 1:
            Led.setColor(LedColor::red);
            break;
        case 2:
            Led.setColor(LedColor::green);
            break;
        case 3:
            Led.setColor(LedColor::yellow);
            break;
        case 4:
            Led.setColor(LedColor::blue);
            break;
        case 5:
            Led.setColor(LedColor::purple);
            break;
        case 6:
            Led.setColor(LedColor::cyan);
            break;
        case 7:
            Led.setColor(LedColor::white);
            break;
      // Don't set a default case, since there appear to be some undocumented
      // values sent fromt the software. We want to ignore those
  }
}
void parseEffect(int data) {
#ifdef DEBUG
  Serial.print("parseEffect: ");
  Serial.println(data);
#endif
    switch (data) {
        case 0:
            Serial.println("bright");
            Led.setEffect(LedEffect::bright);
            break;
        case 1:
            Serial.println("dim");
            Led.setEffect(LedEffect::dim);
            break;
        case 2:
            Serial.println("fast_pulse");
            Led.setEffect(LedEffect::fast_pulse);
            break;
        case 3:
            Serial.println("slow_pulse");
            Led.setEffect(LedEffect::slow_pulse);
            break;
      // Don't set a default case, since there appear to be some undocumented
      // values sent fromt the software. We want to ignore those
  }
}

void setup() {
#ifdef NEOPIXEL
  #ifdef DEBUG
    Led.debugColors();
  #endif
  Led.initStrip();
  // power the button
  digitalWrite(BUTTON_PWR, HIGH);
#else
  Led.setColor(LedColor::no_color);
  Led.setEffect(LedEffect::bright);
#endif

  button.begin(BUTTON_PIN);
  button.setPressedHandler(pressed);
  button.setLongClickDetectedHandler(longClickDetected);
  button.setReleasedHandler(released);

  // Workaround for bug when sending less than 64 bytes of data
  // Since arrays are zero init'd by default we shouldn't have to do this
  // anymore
  /* for (byte i = 0; i < sizeof(rawhidWriteBuffer); i++)
  {
      rawhidWriteBuffer[i] = 0x00;
  } */

  // There was a potential conflict before if you hit the button fast you could
  // read in Garbage data from HID because the buffer would get overwritten by
  // output
  RawHID.begin(rawhidInBuffer, sizeof(rawhidInBuffer));

#ifdef DEBUG
  Serial.begin(115200);
#endif
}

void loop() {
  Led.update();
  button.loop();
  int bytesAvailable = RawHID.available();
  if (bytesAvailable > 0) {
    while (bytesAvailable--) {
      rawhidBuffer[byte_count] = RawHID.read();
      byte_count++;
    }
    // We only care about the first byte.
    int hidData = rawhidBuffer[0];
    int ones = ((byte)hidData / 1) % 16;
    int tens = ((byte)hidData / 16) % 16;

    if ((ones >= 0 && ones <= 7) && (tens >= 0 && tens <= 3)) {
#ifdef DEBUG
      Serial.print("hidData: ");
      Serial.print(hidData, DEC);
      Serial.print(" / 0x");
      Serial.println(hidData, HEX);

      Serial.print("ones: ");
      Serial.print(ones, DEC);
      Serial.print(" / 0x");
      Serial.println(ones, HEX);

      Serial.print("tens: ");
      Serial.print(tens, DEC);
      Serial.print(" / 0x");
      Serial.println(tens, HEX);

      Serial.println();
#endif
      parseColor(ones);
      parseEffect(tens);
    } else {
#ifdef DEBUG
      Serial.print("Invalid/Undocumented data: ");
      Serial.print(ones);
      Serial.print(tens);
      Serial.print("/0x");
      Serial.println(hidData, HEX);
#endif
    }
#ifdef DEBUG
    for (byte i = 0; i < byte_count; i++) {
      Serial.print(rawhidBuffer[i], HEX);
      Serial.print(" ");
    }

    Serial.println();

    Serial.print("Byte Count: ");
    Serial.println(byte_count, DEC);
#endif
    // Reset our byte count once we have read the whole input buffer
    byte_count = 0;
  }
}

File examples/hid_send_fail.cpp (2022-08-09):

// This isn't working, but including for reference
// Button.h and RGBLeh.h were generated at https://www.circuito.io/static/reply/index.html

#include <Arduino.h>
#include "HID-Project.h"
#include <Button.h>
#include <RGBLed.h>

// Pin Definitions
#define PUSHBUTTON_PIN_2	2
#define RGBLED_PIN_B	3
#define RGBLED_PIN_G	5
#define RGBLED_PIN_R	6

// Global variables and defines
#define rgbLed_TYPE COMMON_ANODE
// object initialization
Button pushButton(PUSHBUTTON_PIN_2);
RGBLed rgbLed(RGBLED_PIN_R,RGBLED_PIN_G,RGBLED_PIN_B,rgbLed_TYPE);

// The size of the buffer for the HID device, 64 byte max
// https://github.com/NicoHood/HID/issues/133#issuecomment-533946021
// ************************ Note this doesn't work ****************
// Able to receive data, but not send it back to the PC https://github.com/NicoHood/HID/issues/133
// https://arduino.stackexchange.com/questions/78880/send-custom-hid-values-instead-of-keys
// https://learn.sparkfun.com/tutorials/hid-control-of-a-web-page/all

uint8_t rawhidData[64];

void setup()
{

  // fill rawhdidData with 0s
  for (int i = 0; i < sizeof(rawhidData); i++) {
    rawhidData[i] = 0;
  }
  pushButton.init();
  rgbLed.turnOff();
  // pinMode(LED_BUILTIN, OUTPUT);
  Serial.begin(9600);
  Keyboard.begin();
  RawHID.begin(rawhidData, sizeof(rawhidData));
}
void loop()
{
  // if button.onpress == true
  if(pushButton.onPress())
  {
    // rgbLed.setRGB(50,50,50);
    // rawhidData[0] = 0x00; 
    // rawhidData[1] = 0x04;
    // Serial.print("uploading data: ");
    // Serial.print(rawhidData[0]);
    // Serial.print(",");
    // Serial.print(rawhidData[1]);
    // RawHID.write(rawhidData, sizeof(rawhidData));
    Serial.println("Sending 0x04 to pc");
    Keyboard.write(0x04);
    delay(1000);
    Keyboard.write(0x02);
    Keyboard.write(0x00);
    Keyboard.releaseAll();
  }

  // Check if there is new data from the RawHID device
  auto bytesAvailable = RawHID.available();
  if (bytesAvailable)
  {
    // digitalWrite(LED_BUILTIN, HIGH);

    // Mirror data via Serial
    while (bytesAvailable--) {
      auto data = RawHID.read();

      Serial.println(data);
      // Print out data
      // for (auto i = 0; i < sizeof(data); i++) {
      //   Serial.print(data[i], HEX);
      //   Serial.print(" ");
      // }


      // red = 0x01
      if (data == 1)
      {
        rgbLed.setRGB(255,0,0);
      }
      // green = 0x02
      if (data == 2)
      {
        rgbLed.setRGB(0,255,0);
      }
      // yellow = 0x03
      if (data == 3)
      {
        rgbLed.setRGB(255,255,0);
      }
      // blue = 0x04
      if (data == 4)
      {
        rgbLed.setRGB(0,0,255);
      }
      // purple = 0x05
      if (data == 5)
      {
        rgbLed.setRGB(255,0,255);
      }
      // cyan = 0x06
      if (data == 6)
      {
        rgbLed.setRGB(0,255,255);
      }
      // white = 0x07
      if (data == 7) 
      {
        rgbLed.setRGB(255,245,255);
      }
      // noColor = 0x00
      if (data == 0)
      {
        rgbLed.turnOff();
      }

    }
    // digitalWrite(LED_BUILTIN, LOW);
  }
}

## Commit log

2022-08-10 remove buttons
2022-08-10 easy button
2022-08-10 button presses working
2022-08-10 working button press
2022-08-11 working leds
2022-08-11 fix purple, add license
    [main.cpp]
2022-08-17 add working buttons
2022-08-17 add button
2022-08-24 Add CAD
2022-08-27 build all boards
2022-09-08 add v0.2
    [PCB.stl]
2023-03-21 added button power
2023-04-23 Quick bug fix for Issue #5
    [main.cpp]
